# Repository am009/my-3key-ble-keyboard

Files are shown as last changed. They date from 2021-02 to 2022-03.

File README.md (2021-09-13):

# 3key-bluetooth-mechanical-keyboard

Based on a tiny esp32 board TTGO T-Display. Draw a simple extension PCB with key switches for it. Connect with two row pins, and put battery in between.

基于TTGO T-Display这个小巧的开发板，通过排针排母连接一个带机械键盘轴的PCB，正好中间的位置放电池。本来打算放四个键，不太放得下就砍掉了一个键。

本项目的目的是学习使用Kicad，尝试画PCB，同时满足自己对小巧的蓝牙键盘的需求。没想到PCB双层板打样这么便宜，5块钱5张，那还用什么洞洞板，飞什么线，自己画拓展板去。这次拓展接线完全就是简单的IO口接轴接GND，甚至用esp32的内部上拉，走线甚至只用了单面。本来想尝试尝试esp_idf开发的，最后还是选择了Arduino IDE。。。比较简单。

Update:
 
- 休眠前主动断开连接，不必等到超时才断开 - ok
- 电量显示有时不稳定，会显示电量为0% - ok
- 低电量闪烁提醒。- 没有合适的板载led

## Reason
背anki用。三个键分别是Enter（good 绿色按钮）数字键1 (again 红色) 数字键2 (hard 灰色)
Make a small ble keyboard for Anki flashcards.
I mount my phone over my pillow, thinking about some way to control my phone. I tried using my Logitech bluethooth keyboard and feel great. When using Ankidroid to remember vocabularies, I found myself needing a tiny bluetooth keyboard.
the three key is set to Enter(for pressing the green(good) button), num 1(for red(again) button), and num 2(for gray(hard) button).

## Hardware

物料：

1. 电池最后选了~~802040（8mm厚，20mmx40mm） 800mah，勉强塞下~~(update 2021.9.13 前两天电池被键轴焊脚戳破了，改用602040锂电池)。续航能力7-10天。是1.25mm 2P 正向接口。 15元两个包邮
2. 买了4个cherry 茶轴和4个灰色键帽。 带邮费26。
3. TTGO T-Display 47元（带排针），加两个12P排母。
4. 自备烙铁焊锡丝。

能够自定义三个键，暂不支持复杂的宏操作。

TTGO自带的按键一个设置为查看电量，一个设置为休眠和开机。

可以自定义蓝牙显示的名称，能够通过蓝牙显示电量信息。

打样打了5块，只用了一块，可以联系我。

唤醒方面原本是通过三个键同时按下唤醒的，最后还是改成了屏幕下方的按钮休眠。

## PCB

PCB设计使用Kicad. 用了下面的组件

[tmk - keyboard_parts](https://github.com/tmk/keyboard_parts.pretty) 键轴

[ttgo_esp32](https://github.com/BravoRoot/ttgo-tdisplay-kicad) for ttgo t-display component.

[MX_Alps_Hybrid](https://github.com/ai03-2725/MX_Alps_Hybrid) 键轴

[ttgo t-display 3d model](https://grabcad.com/library/lilygo-ttgo-t-display-esp32-1) 可以测量尺寸

画PCB的时候为了保险就留了上拉电阻的位置，最后确实不用接。

## Firmware

最后选择了Arduino IDE开发。安装：

1. [Arduino 蓝牙键盘库](https://github.com/T-vK/ESP32-BLE-Keyboard) 
2. [TTGO的屏幕支持库](https://github.com/Xinyuan-LilyGO/TTGO-T-Display) 
3. 按照`Three_Key_TTGO\BleKeyboard.cpp.patch`和`Three_Key_TTGO\BleKeyboard.h.patch`修改ESP32-BLE-Keyboard库(为了支持即时断开连接)

开发板选择 ESP32 Dev Module,在PSRAM选项中选择Disable， Flash Size 选项中选择4MB ，其它保持默认

## TODO

1. 还是有外部上拉比较好，deep-sleep模式下负责内部上拉的RTC外设部分就可以休眠了。

## 图片展示

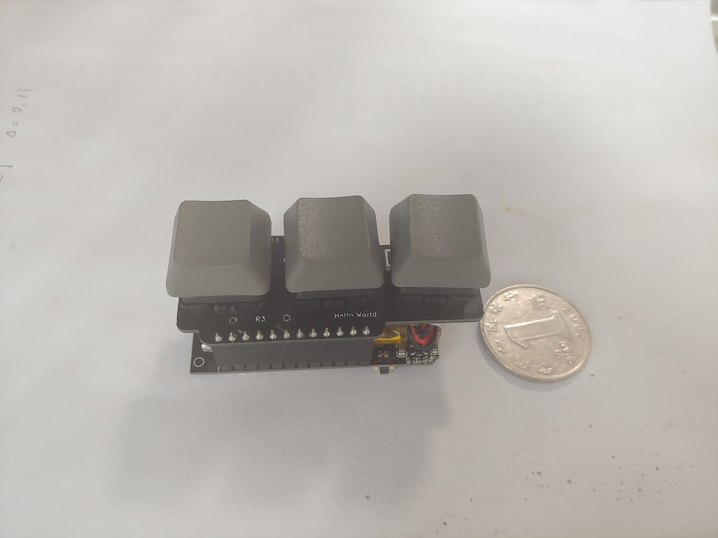
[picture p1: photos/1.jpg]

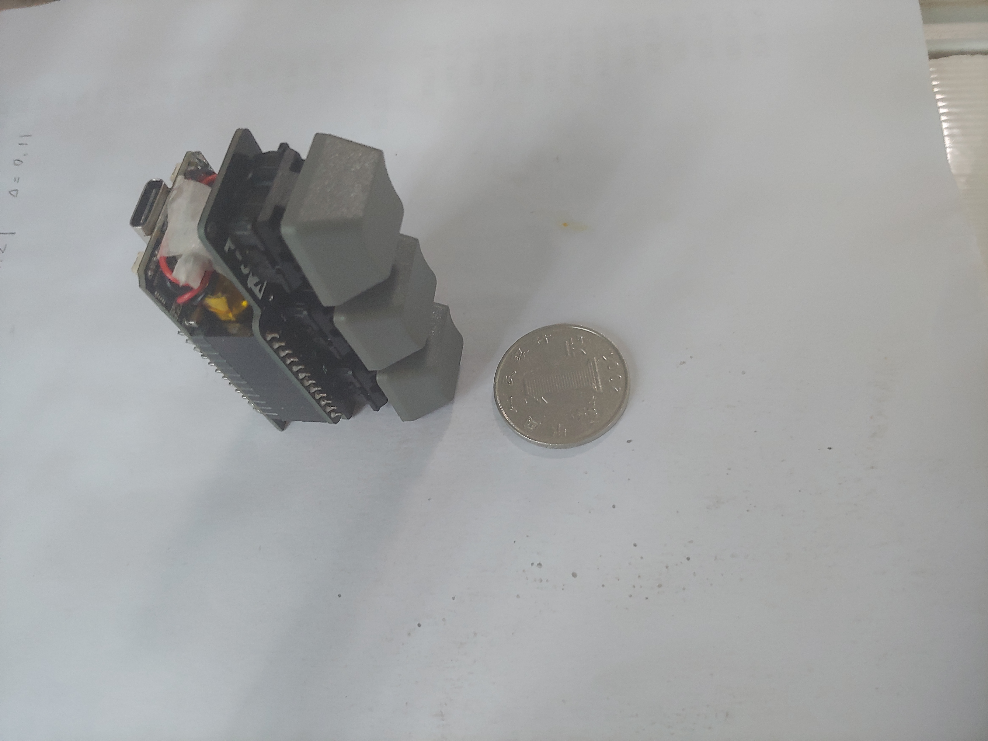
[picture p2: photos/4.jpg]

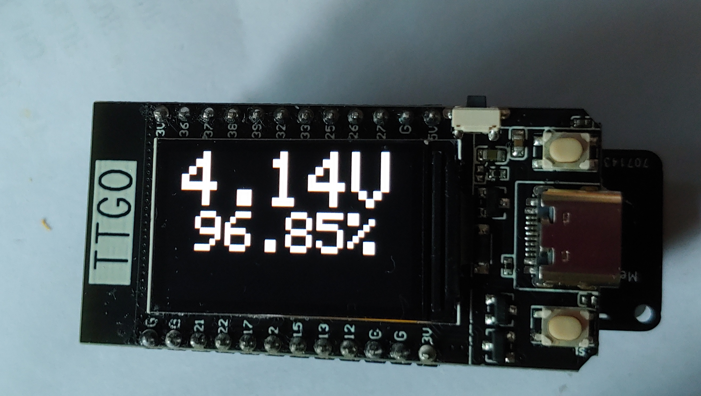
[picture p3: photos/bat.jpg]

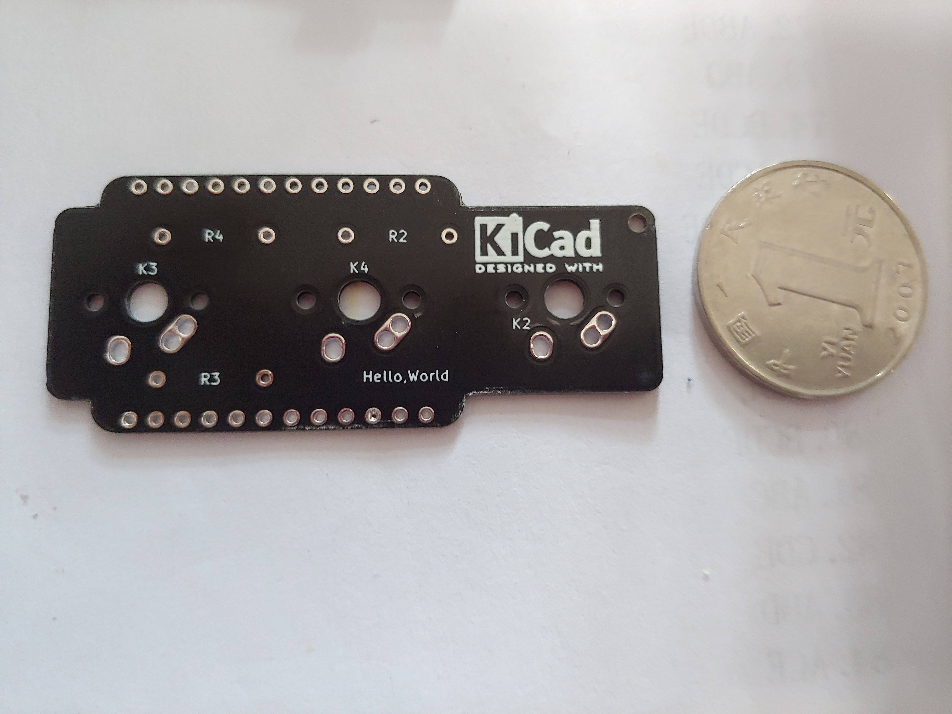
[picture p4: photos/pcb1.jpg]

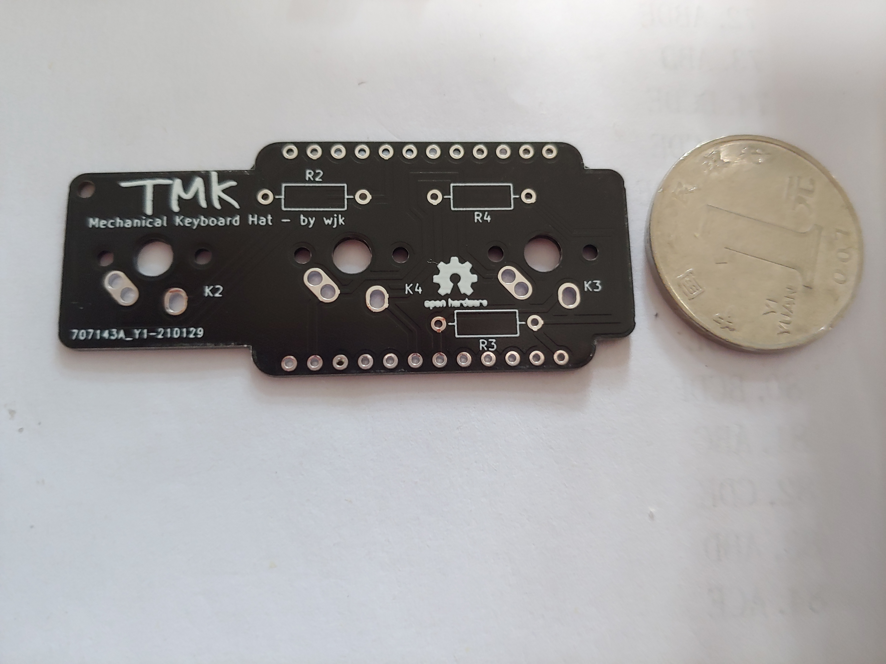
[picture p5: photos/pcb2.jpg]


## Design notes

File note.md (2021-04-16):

# 4-key TTGO T-Display 蓝牙机械键盘

ttgo屏幕面朝外，（长）排针连接底板，中间空隙放电池，另一面机械键盘轴朝外。

排母的焊脚刺手怎么办？。。热熔胶？

## 材料

电池：大概选20mm宽，40/50mm长的3.7v锂电池。

TTGO T-Display 40元？ 排母一起买了

键轴，键帽

PCB打样 5元？

电池：

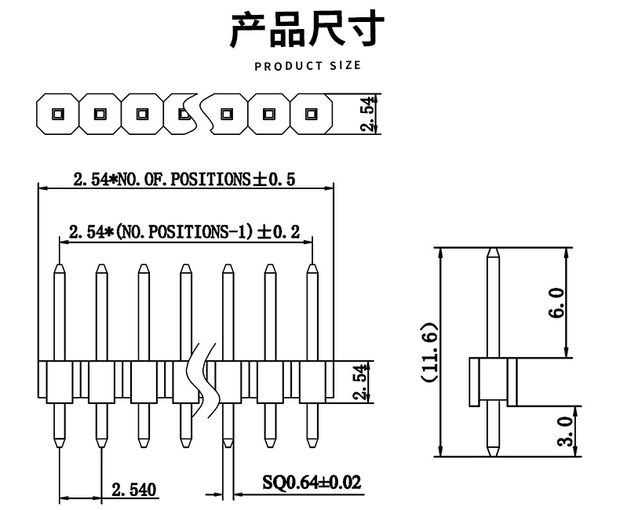
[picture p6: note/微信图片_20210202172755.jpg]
微信图片_20210202172755


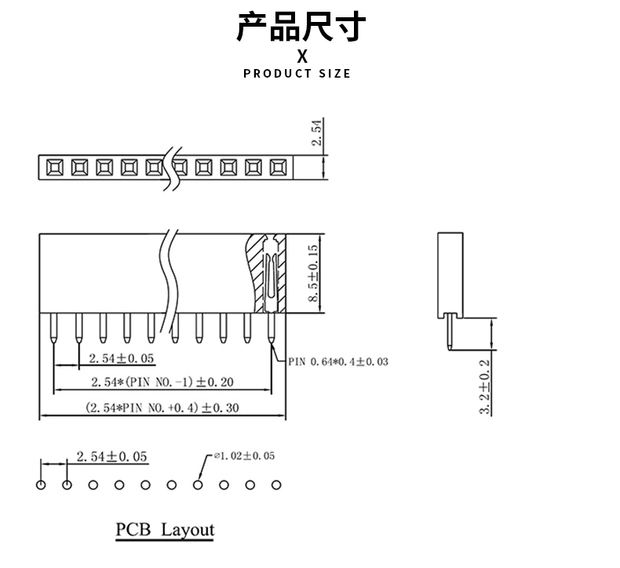
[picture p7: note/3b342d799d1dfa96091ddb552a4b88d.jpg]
3b342d799d1dfa96091ddb552a4b88d


排母，长排针？排母8.5mm的塑料位，电源接头算3mm，紧靠电源接头有41mm到底部。买厚度5mm，长40mm的应该可以。

不保守的话可以买：8mm厚35mm长，或者5mm厚55mm长。

可以考虑最后完成了再买电池。

没想到键盘轴的焊脚突出了这么多。。。

排针高度

## 接线

[引脚选择](https://randomnerdtutorials.com/esp32-pinout-reference-gpios/)：避开的引脚：

1. 避开引脚2 似乎连了内部led
2. 避开34-39的input only脚，没有内部上下拉
3. 使用RTC GPIO可以在睡眠时唤醒
4. 34 to 39 can’t generate PWM 没啥关系
5. must be HIGH during boot
6. 要不要把spi口让开？没必要
7. Capacitive touch：4 0 2 15 13 12 14 27 33 32

就选13 15 32 33 或者 32 33 25 26

接线，看看是否可以内部上拉，应该可以。但是留出电阻的位置

按键接线

有内部上拉就可以直接接地，没有则要每路接个电阻了。考虑留大电阻位置，没有内部上拉再加电阻。

#### 选轴

红轴或者茶轴了。都声音不大，红轴段落感更强。

封装选Mx_Alps_Hybrid -1u -noled

电阻应该是1/4W的，选AXIAL-0.4， 10.2mm

#### 焊接电池

还是先焊电池吧。。。也找纸胶带来，把焊点封住。怎么让两个线呆在一起方便焊？把外皮撕掉点吧。。。撕不开。。。找打火机吧。。。麻了

### PCB设计

排母和按键的方向不同，不能单面，还是双面吧，两面都有焊盘才好焊接。 

#### 边缘

1. 都圆角，不割手
2. 机械键盘轴大概是15\*15？还是14\*14。还是突出来和键帽齐平吧。
3. 多写点字

### pinmap

GPIO13 - K2 - 底部是TMK字样

GPIO33 - K4

GPIO32 - K3

## 软件

### 索引

ESP32库代码在 `AppData\Local\Arduino15\packages\esp32` 。VScode打开以搜索库。

左侧按键GPIO 0 （IO0），右侧按键 GPIO 35（KEY1）自带电阻拉高到3V3。

先安装ESP32开发板到arduino，然后 [裸机蓝牙键盘库](https://github.com/asterics/esp32_mouse_keyboard) ，然后是[TTGO的屏幕支持库](https://github.com/Xinyuan-LilyGO/TTGO-T-Display)。

### 基于Arduino

[Arduino 蓝牙键盘库](https://github.com/T-vK/ESP32-BLE-Keyboard) 虽然不是很爽，还是赶紧做出一个能用的出来。

1. 设置CPU频率 -ok 直接选
2. debounce按键
3. 使用GPIO的中断而不是轮询。 ok 
4. 增加计时器，时间过长后休眠
5. 休眠后蓝牙重连测试：
6. 使用屏幕

没想到我也遇到了需要freeRTOS的一天。ESP32有两个核心，arduino IDE只运行在core 1，core 0闲着。只要我分工合理，就不需要互斥。freeRTOS应该也不会抢占。

首先弄清楚中断注册了之后在哪个核上处理：[看文档](https://docs.espressif.com/projects/esp-idf/en/latest/esp32/api-reference/system/intr_alloc.html) 应该是谁分配谁处理吧。

那就让core0专门处理蓝牙，core1专门处理中断，调用task_create给core0吧

[简单的freertos教程](https://savjee.be/2020/01/multitasking-esp32-arduino-freertos/) 

### 按键防抖

麻了，一生之敌

普通的按键防抖基于一个无限采样的循环，当值开始变化的时候记录变化时间，如果当前时间距离上次变化时间超过了防抖动时间，则此时采样的结果稳定。剩下的就是判断键盘状态变化。

问题的本质在于，需要在抖动结束的时候及时发现已经过了debounce时间，而普通的中断只能发现电平变化。

所以一个中断加一个timer就完美了？？！！！timer资源够多吗？

是否搞个互斥，保证每次只有一个isr实例运行？或者用一个中断例程处理三个键的采样？

最终：使用timer防抖，在每次状态改变的时候重置timer，在一定时间后采样。使用3个freertos的 timer，使用同一个处理服务函数，通过*pvTimerID* 区分是哪个键。初始化的时候静态分配timer，并立刻停止timer。在收到Change中断的时候reset。

WE可能是wakeup enable的意思

### 蓝牙与按键

只要按下去，松开之前等几秒就没有问题。看来是蓝牙那边发送得有点慢啊。

似乎我面临的就是重入问题？，只要让timer互斥一下？也就是当前timer没有结束，就reset了timer，timer再次运行？还是什么？还是启动了多个timer的callback?

算了，还是给蓝牙那边搞个队列，搞个专门处理发送的task吧。

居然就能用了。。。

### sleep

1. 普通的GPIO wakeup还是算了，只能light sleep。
2. ULP协处理器需要编写汇编，还是算了。
3. 使用内部上拉需要启动RTC外设的电源域，增加一点点耗电？

touchpad唤醒不太懂，我按键能当touch吗？所以主要的两个唤醒源就是ext0：单GPIO唤醒，ext1：多GPIO any_high/all_low唤醒。也就是要么三个键全部按下唤醒，要么单个键唤醒。

有点感觉这功能甚至不如电源开关，还不耗任何电。

话说三个键全部按下唤醒似乎可以防误触啊。不错，就用这个了。

首先设置变量保存上一次使用的时间。如果超过4分钟没有使用就休眠。就用loop循环去检测。

休眠醒来似乎和重启没什么区别啊。。。因此在setup函数之前设置打印唤醒原因用于debug，然后对相关的引脚调用rtc_gpio_deinit重新配置。loop函数休眠前设置唤醒源，并设置好引脚拉高即可。

### 电池管理

[FactoryTest.ino](https://github.com/Xinyuan-LilyGO/TTGO-T-Display/blob/master/TFT_eSPI/examples/FactoryTest/FactoryTest.ino) 这里有代码

然后就是看怎么发送给手机那边了。如何蓝牙发送电池电量，和改名字？？TODO

电量计算问题：最低电压是3V，这时候得赶紧充电。，满电就是4.2v了。ttgo板子上的电源管理芯片有过充保护，但是过放保护不知道有没有。。。看来长时间不用还是要取下电池啊，不然伤电池。

```
uint16_t v = analogRead(ADC_PIN);
float battery_voltage = ((float)v / 4095.0) * 2.0 * 3.3 * (vref / 1000.0);
```

计算公式怎么来的？电路中似乎有个电压减半，那ESP32的测量范围就是。1.5-2.1v了。ADC_ATTEN_DB_11可以测量到2.6v电压。12bit的adc也就只有4096种取值。TODO

不是应该用esp_adc_cal_raw_to_voltage吗。。。难道他们把原理提取出来了？？

另外还有两个小按钮，就不给他们搞什么timer了，麻了，就设置个bool的变量吧，如果loop函数检测到了就打开屏幕显示一下电量。另外一个按钮就用来直接进入睡眠。

TODO:

1. 显示电量前再检测一下电池电压。每次休眠启动的时候检测的电压都是1.几v。
2. 看看是不是ADC使用得不对，我现在电压度数比万用表高了0.14v，怪不得我的电压爆炸。
3. 电池电压转为电量百分比，显示在蓝牙和屏幕那边，看看蓝牙设备名称怎么改

4. 电池还不很耐用啊，看看是不是有什么提升空间，在工作时而不是休眠时。

电池电压和电量绝对不是线性关系啊。。。需要的是电压转电量的表。..

搞个[在线曲线拟合](http://www.qinms.com/webapp/curvefit/cf.aspx)哈哈哈。

曲线不理想啊，分段拟合吧，两个二次曲线

```
100%----4.20V
0.14
90%-----4.06V
0.08v
80%-----3.98V
0.06v
70%-----3.92V
0.05
60%-----3.87V
0.05
50%-----3.82V
0.03
40%-----3.79V
0.02
30%-----3.77V
0.03
20%-----3.74V
0.06
10%-----3.68V
0.23
5%------3.45V
0.45
0%------3.00V
```

```
a(x+d)2+e
-496.636+238.432 x-28.05 x^(2)    3.79<x<4.2
=-28.05(x-4.25)^(2)+10
2938.5-1599.55x +217.75*x^(2)     3.68<x<3.79
217.75(x-3.673)^(2)+1
12.84 + -8.97*x +1.563*x^(2)      x<3.68
1.563 (x-2.87)^(2)-0.03
```

Curve(x,-28.05(x-4.25)^(2)+10,x,3.79,5)
Curve(x, 217.75(x-3.673)^(2)+1,x,3.68,3.79)
Curve(x, 1.563 (x-2.87)^(2)-0.03,x,2.5,3.68)

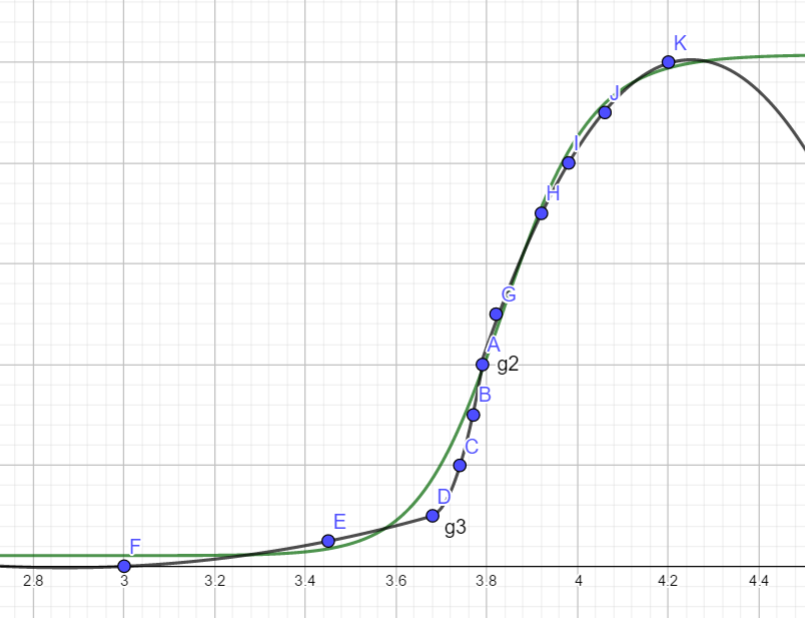
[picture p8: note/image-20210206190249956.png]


### 屏幕

把屏幕用起来，正好ttgo这板子上还有两个键，就用来显示几秒电量然后关掉吧。

### deep sleep

耗电似乎还是主要是使用状态下。

内部上下拉和外部不一样时的漏电问题？？

ext1才能关闭rtc的外设供电。两个板子上的按钮，IO0是悬浮的，KEY1是自带上拉的。IO0也是Flash按钮。

似乎没有什么改进的余地了。tft的sleep也已经用上了。或许打从一开始就不用tft比较好。只要不初始化，电量就一定是最低的。不，现在已经优化得可以了，已经没什么余地了。

休眠时电量保持：

1. tft显示屏方面达到完全休眠。tft的DISPOFF和SLEEP都用上了。除非完全不用显示屏。
2. RTC GPIO isolate方面目前似乎没有漏点的引脚。
3. ESP32也是最强的deep sleep模式了。
4. 自身体验上，休眠确实不怎么耗电，已经挺好的了。

工作模式下电量优化：

1. esp32方面已经是80mhz的最低频率了。

2. wifi蓝牙是一体的，不好禁用吧

3. [在modem sleep模式下保持蓝牙连接](https://github.com/espressif/esp-idf/issues/947#issuecomment-500312453) 需要外部晶振，软件配置。不知道支不支持。BLE wakeup？

   change TX power？算了。听说降频到40mhz会有点问题，还是算了，说明不能休息，休息了蓝牙就不能正常工作了。就这样吧。。

优化电量曲线：

1. 似乎3.9v附近电量掉得确实太快了。。？

展望：

1. ESP32-S3和ESP32-C3（risc-v）都还买不到。。。

## 休眠唤醒debug

1. 问题只出现在，睡眠后，试图在接电池的情况下唤醒。
2. reset可以唤醒。
3. 不是上拉的问题，也不是唤醒了瞬间睡眠的问题。
4. 唤醒失败后，再接上电也不能唤醒。

RTC协处理器可能彻底关了？？

试图在接电池的情况下唤醒的时候，发生了些什么。

电池本身状态正常，板子单独接电也正常，问题应该是板子的供电部分，或者是电池和板子的协作上。

那暂时躺平吧，直接取消任何唤醒，用reset唤醒。

2021年4月16日 再次Debug，这次Reset键被压坏了，所以买了个新板子。发现单接电池直接出现休眠唤醒问题。插电就没问题。可能真的是：

1. 电池问题吧。。。
2. 代码问题

代码也被我改乱了，先备份一份现在的代码，然后回退到之前的稳定代码试试。大概是不行的，然后再把新板子的电源端子线接到另外一块电池上，先不急着焊排针了。

麻了，换了电池，问题依旧。。。无论是GPIO35唤醒，还是三个键同时按下，在电池这次都无法唤醒了。板子也换了，电池也换了，旧版代码也用过了，怎么就是不行呢？

- 可能是SDK版本更新了？也不是，我是用着用着就突然无法唤醒的。
- debug需要不给板子供电的串口，或者动态的芯片调试器了？。。。睡眠唤醒怎么能debug啊。。。。。考虑写一个最小的复现问题的例子单独试试。

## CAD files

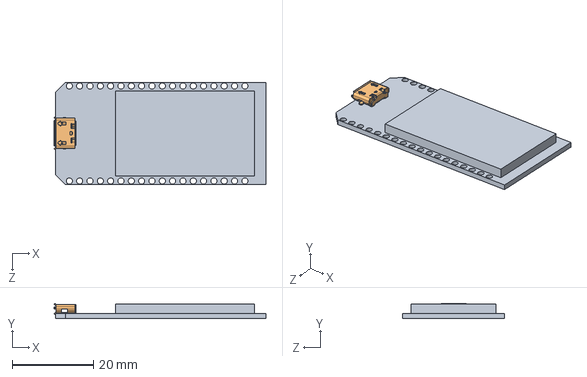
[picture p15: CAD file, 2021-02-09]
board/ttgo-tdisplay-kicad-master/TTGO1.SLDASM
52.1 x 3.77 x 25.1 mm
TTGO-ESP32LORA
microusb

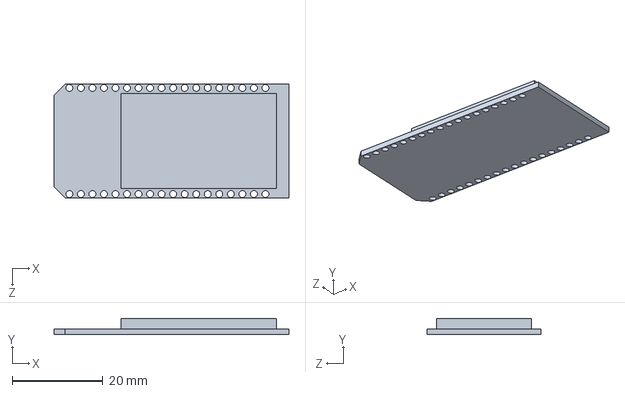
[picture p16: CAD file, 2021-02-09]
board/ttgo-tdisplay-kicad-master/TTGO-ESP32LORA.SLDPRT
51.8 x 3.55 x 25.1 mm

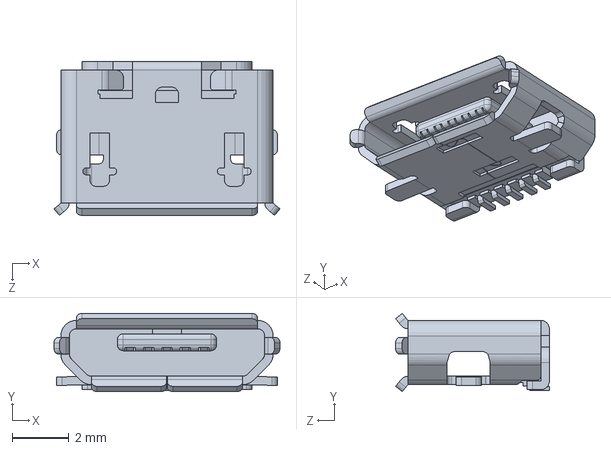
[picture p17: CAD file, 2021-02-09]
board/ttgo-tdisplay-kicad-master/microusb.SLDPRT
7.98 x 2.76 x 5.43 mm

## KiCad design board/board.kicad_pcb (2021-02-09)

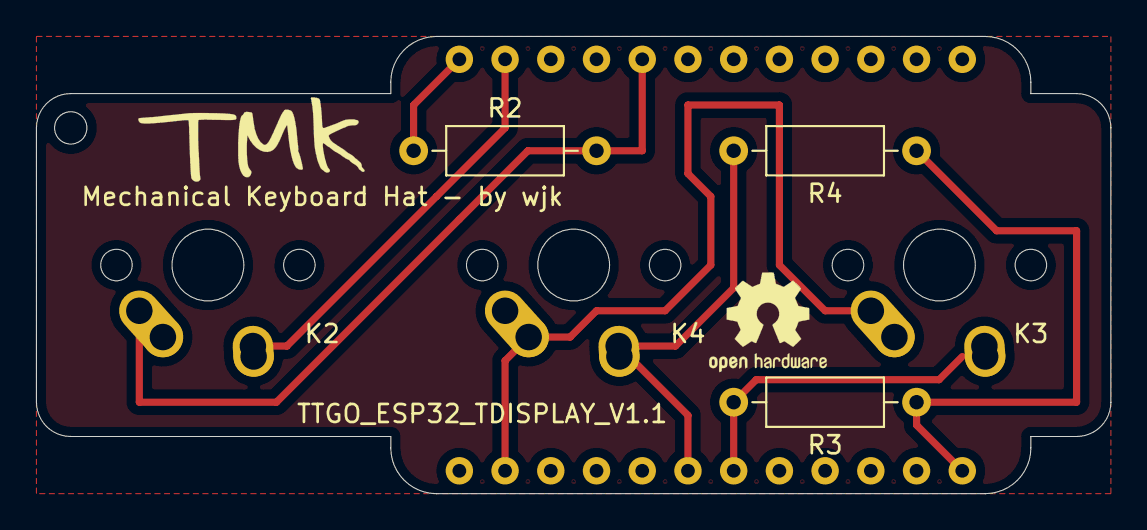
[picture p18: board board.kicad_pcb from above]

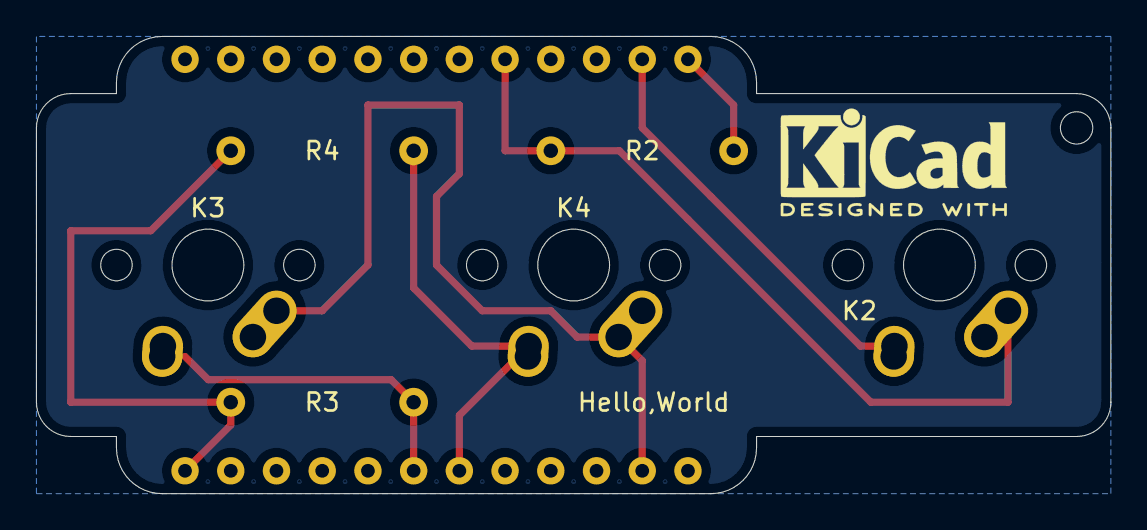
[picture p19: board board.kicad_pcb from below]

Board: 2 copper layers, 59.7 x 25.4 mm, 7 parts (3 on the bottom side), 7 nets.

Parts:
K2, K3, K4: KEYSW; MX-1U-NoLED
R2, R3, R4: R; R_Axial_DIN0207_L6.3mm_D2.5mm_P10.16mm_Horizontal
TTGO1: TTGO_ESP32_TDISPLAY_V1.1; TTGO_ESP32_TDisplay_v1.1

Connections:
unnamed: K2.2, TTGO1.23
unnamed: K2.1, R2.2, TTGO1.20
unnamed: K3.1, K4.1, TTGO1.2
unnamed: K3.2, R3.2, TTGO1.7
unnamed: K4.2, R4.2, TTGO1.6
unnamed: R2.1, TTGO1.24
unnamed: R3.1, R4.1, TTGO1.12

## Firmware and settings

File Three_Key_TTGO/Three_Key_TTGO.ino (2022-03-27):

#include <Arduino.h>
#include "key_interrupt.h"
#include "ble_kb.h"
#include <driver/rtc_io.h>
#include "utils.h"

#include <TFT_eSPI.h>
#include <SPI.h>

QueueHandle_t key_queue;
uint32_t last_use = 0; // 蓝牙发送时更新，用于loop中判断是否需要休眠
uint32_t last_update = 0;
float battery_voltage = 0;
float percentage = 0;
bool butr_pressed = false;
bool butl_pressed = false;

// 负责处理队列里的蓝牙发送请求
void ble_send_task(void *p)
{
  if (key_queue == NULL)
  {
    Serial.printf("ERROR: ble_send_task started before queue init.\n");
    return;
  }
  uint8_t c = 0;

  do
  {
    if (xQueueReceive(key_queue, &c, portMAX_DELAY) != pdTRUE)
    {
      Serial.printf("ERROR: key_queue Receive failed.\n");
      continue;
    }
    if (bleKeyboard.isConnected())
    {
      bleKeyboard.write(c);
    }
    last_use = millis();
  } while (true);
}

// ("TTGO 3-Key Mechanical Keyboard", "warrenwjk", 100)
BleKeyboard bleKeyboard("TTGO 3-Key Mechanical Keyboard", "warrenwjk", 76);
TFT_eSPI tft = TFT_eSPI(135, 240); // Invoke custom library
static uint8_t ble2key[NUM_KEYS] = {KEY_RETURN, '1', '1'}; // 在这里修改按键值
void on_key_int(uint32_t p)
{
  bool current_state = (((uint32_t)p % 2 == 1) ? true : false);
  uint32_t ind = ((uint32_t)p >> 1);
  // Serial.printf("key pressed p: %d.\n", (uint32_t)p);

  if (current_state != 1)
  {
    return;
  }

  if (ind >= NUM_KEYS)
  {
    Serial.printf("key press index out of bound.\n");
    return;
  }

  // Serial.printf("key %c pressed\n", ble2key[ind]);
  if (xQueueSend(key_queue, &ble2key[ind], 0) != pdPASS)
  {
    Serial.printf("key enqueue failed.\n");
  }
}

void IRAM_ATTR butr_isr(void *arg)
{
  butr_pressed = true;
}

void IRAM_ATTR butl_isr(void *arg)
{
  butl_pressed = true;
}

void setup()
{
  butl_pressed = false;
  butr_pressed = false;
  Serial.begin(115200);
  print_wakeup_reason();

  for (uint32_t i = 0; i < NUM_KEYS; i++)
  {
    timers[i] = xTimerCreate("KeyStateSampler", pdMS_TO_TICKS(30), pdFALSE, (void *)(i), sampler_callback);
    if (timers[i] == NULL)
    {
      Serial.printf("KeyStateSampler timer create failed!\n");
    }
    buts[i].cb = on_key_int;
  }
  for (uint32_t i = 0; i < NUM_KEYS; i++)
  {
    rtc_gpio_deinit((gpio_num_t)(pins[i]));
  }
  pinMode(BUT1_PIN, INPUT_PULLUP);
  attachInterruptArg(BUT1_PIN, key_isr, &buts[0], CHANGE);
  pinMode(BUT2_PIN, INPUT_PULLUP);
  attachInterruptArg(BUT2_PIN, key_isr, &buts[1], CHANGE);
  pinMode(BUT3_PIN, INPUT_PULLUP);
  attachInterruptArg(BUT3_PIN, key_isr, &buts[2], CHANGE);
  pinMode(BUTR_PIN, INPUT);
  attachInterruptArg(BUTR_PIN, butr_isr, NULL, FALLING);
  pinMode(BUTL_PIN, INPUT_PULLUP);
  attachInterruptArg(BUTL_PIN, butl_isr, NULL, FALLING);

  Serial.printf("Interrupt setup finished at %d ms.\n", millis());

  bleKeyboard.begin();
  key_queue = xQueueCreate(10, sizeof(uint8_t));
  if (key_queue == NULL)
  {
    Serial.printf("key_queue create failed!\n");
  }
  if (xTaskCreate(ble_send_task, "ble_send_task", 10000, NULL, tskIDLE_PRIORITY, NULL) != pdPASS)
  {
    Serial.printf("ble_send_task create failed!\n");
  }

  // Wait for stable voltage.
  vTaskDelay(100 / portTICK_PERIOD_MS);
  battery_adc_init();
  battery_voltage = battery_get_voltage();
  percentage = battery_percentage(battery_voltage);
  Serial.printf("Battery voltage is %f v. %f%%\n", battery_voltage, percentage);
  bleKeyboard.setBatteryLevel(roundf(percentage));
  
  Serial.println("BLE started.\n");
}

void loop()
{
  if (error_code != 0)
  {
    Serial.printf("error\n");
  }
  uint32_t current = millis();
  if (current - last_use > SLEEP_DELAY_MS || butr_pressed)
  {
    esp_err_t sleep_res;
    #if 1
    sleep_res = esp_sleep_enable_ext1_wakeup(GPIO_SEL_35, ESP_EXT1_WAKEUP_ALL_LOW);
    if (sleep_res != ESP_OK) {
      Serial.println("[Error] esp_sleep_enable_ext1_wakeup Error!");
    }
    // 完全不需要 rtc_gpio_pullup_en(GPIO_NUM_35); ，因为自带上拉电阻。
    #else
    // 使用三个键同时按下作为唤醒方式。
    sleep_res = esp_sleep_enable_ext1_wakeup(GPIO_SEL_13 | GPIO_SEL_32 | GPIO_SEL_33, ESP_EXT1_WAKEUP_ALL_LOW);
    if (sleep_res != ESP_OK) {
      Serial.println("[Error] esp_sleep_enable_ext1_wakeup Error!");
    }
    sleep_res = esp_sleep_pd_config(ESP_PD_DOMAIN_RTC_PERIPH, ESP_PD_OPTION_ON);
    if (sleep_res != ESP_OK) {
      Serial.println("[Error] esp_sleep_pd_config Error!");
    }
    for (uint32_t i = 0; i < NUM_KEYS; i++)
    {
      sleep_res = rtc_gpio_pullup_en((gpio_num_t)(pins[i]));
      if (sleep_res != ESP_OK) {
        Serial.println("[Error] rtc_gpio_pullup_en Error!");
      }
    }
    #endif
    Serial.println("Entering deep sleep...");
    bleKeyboard.end();
    vTaskDelay(200 / portTICK_PERIOD_MS);
    esp_deep_sleep_start(); // not return
  }
  if (current - last_update > UPDATE_DELAY_MS)
  {
    last_update = current;
    // 更新电池电量
    battery_voltage = battery_get_voltage();
    float temp_percent = battery_percentage(battery_voltage);
    if (temp_percent != 0.0f)
    {
      percentage = temp_percent;
      bleKeyboard.setBatteryLevel(roundf(percentage));
    }
    else
    {
      Serial.printf("Anomalous battery voltage auto-update: %f v. %f%%\n", battery_voltage, percentage);
    }
  }
  if (butl_pressed)
  {
    battery_voltage = battery_get_voltage();
    float temp_percent = battery_percentage(battery_voltage);
    if (temp_percent != 0.0f)
    {
      percentage = temp_percent;
      bleKeyboard.setBatteryLevel(roundf(percentage));
    }
    else
    {
      Serial.printf("Anomalous battery voltage but-press: %f v. %f%%\n", battery_voltage, percentage);
    }
    tft.init();
    tft.setRotation(1); //横
    String voltage = String(battery_voltage) + "V";
    String p = String(percentage) + "%";
    tft.fillScreen(TFT_BLACK);
    tft.setTextDatum(MC_DATUM);
    tft.setTextSize(7);
    tft.drawString(voltage, tft.width() / 2, 0);
    tft.setTextSize(5);
    tft.drawString(p, tft.width() / 2, 75);
    vTaskDelay(3000 / portTICK_PERIOD_MS);
    digitalWrite(TFT_BL, LOW);
    tft.writecommand(TFT_DISPOFF);
    tft.writecommand(TFT_SLPIN);

    bleKeyboard.setBatteryLevel(roundf(percentage));

    butl_pressed = false;
  }
  vTaskDelay(300 / portTICK_PERIOD_MS);
}

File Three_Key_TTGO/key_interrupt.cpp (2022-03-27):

#include <Arduino.h>
#include "key_interrupt.h"
#include "ble_kb.h"

// Button buts[NUM_KEYS] = {{0, false, &on_key_int}, {0, false, &on_key_int}, {0, false, &on_key_int}}; // k2 k4 k3
Button buts[NUM_KEYS] = {0};
uint32_t pins[NUM_KEYS] = {13, 33, 32};
const char *keynames[NUM_KEYS] = {"K2", "K4", "K3"};
uint32_t error_code = 0;
TimerHandle_t timers[NUM_KEYS];

void IRAM_ATTR key_isr(void *arg)
{
  Button *s = static_cast<Button *>(arg);
  uint32_t ind = (s - buts);
  if (xTimerResetFromISR(timers[ind], NULL) != pdPASS)
  {
    error_code = 1;
  }
}

void sampler_callback(TimerHandle_t xTimer)
{
  bool currentState = 0;

  uint32_t ind = (uint32_t)pvTimerGetTimerID(xTimer);
  Button *s = &buts[ind];
  currentState = !digitalRead(pins[ind]);

  if (currentState != s->state)
  {
    s->state = currentState;

    if (s->cb == nullptr)
    {
      Serial.printf("Key %s has null callback !\n", keynames[ind]);
    }
    else
    {
      uint32_t arg = (ind << 1) + (currentState ? 1 : 0); //{ind, currentState};
      // xTaskCreate(*(s->cb), "key_cb", 20000, (void*)arg, tskIDLE_PRIORITY, NULL);
      (*(s->cb))(arg);
    }

    if (currentState == true)
    {
      // pressed
      // Serial.printf("Key %s Pressed !\n", keynames[ind]);
    }
    else
    {
      // released
      // Serial.printf("Key %s Released !\n", keynames[ind]);
    }
  }
}

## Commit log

2021-02-09 first commit.
    [TTGO-ESP32LORA.SLDPRT, TTGO1.SLDASM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]
2021-02-09 Add geogebra voltage to battery percentage file.
2021-02-27 Fix unstable battery percentage.
    [Three_Key_TTGO.ino]
2021-03-15 Unstable battery voltage finally fixed. Update setup section in readme.
    [Three_Key_TTGO.ino]
2021-09-13 Update README.md
    Update battery info.
